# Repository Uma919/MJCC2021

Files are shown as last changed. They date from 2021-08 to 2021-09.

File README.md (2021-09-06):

# MJCC2021
## Overview
本リポジトリは[M5Stack Japan Creativity Contest 2021](https://info.switch-science.com/m5stack-creativity-contest-2021)開発リポジトリです．  
This repository is the development repository for [M5Stack Japan Creativity Contest 2021](https://info.switch-science.com/m5stack-creativity-contest-2021).  

紹介動画は下記サムネイルをクリック！  
(https://www.youtube.com/watch?v=NyVpVFx_jqs)

「Microparticle Sound Generator」は，ハウスダストやPM2.5をはじめとした微粒子の量をRGBLEDで可視化し，一定時間における時系列センサデータから音を生成して再生します．  
The Microparticle Sound Generator plays the generated sound with changes in the number of microparticles and also visualizes it by LED.  

## Concept
大気汚染区域では高周波音を流し，空気が澄んだ場所では心地よい？電子音を流すようにして，大気汚染区域に入らないようユーザーをナビゲートします．  
When you enter the air pollution zone, the device starts playing high-frequency sounds. On the other hand, the device will play soothing electronic sounds in the clean air area. So, the device will escort you while avoiding the air pollution zone.  
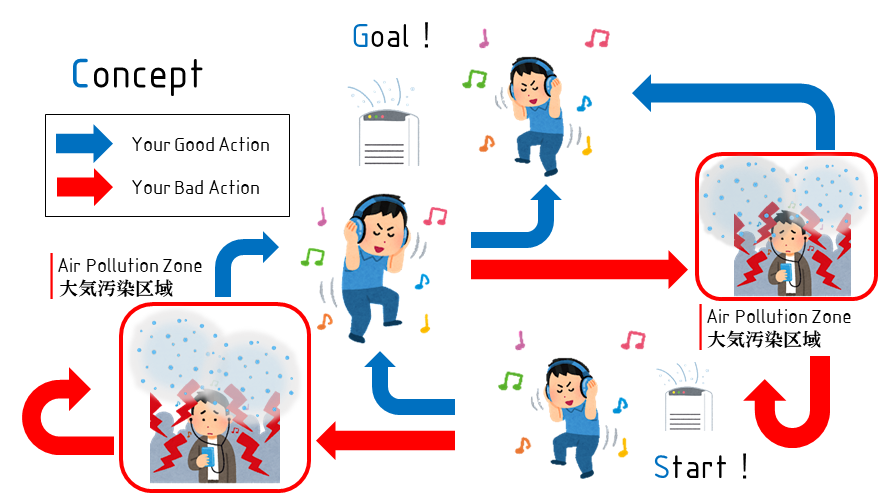
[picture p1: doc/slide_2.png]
  

## Features
本デバイスの主な特徴は，時系列センサデータを音に変換することにあります．これにより，多種多様な音を再生できるだけでなく，時々刻々と音を変化させることが可能となります．  
ATOM Liteには液晶ディスプレイが搭載されていないため、時系列センサデータを視覚的に表示することは困難です．加えて，移動中にモニターを見ることは危険です．従って，時系列センサデータを音に変換し、聴覚で案内することが適切だと考えられます．  
The main feature of the device is that it converts time-series sensor data into sound. It makes that it's possible not only to play a wide variety of sounds but also to change them from time to time.  
Since "ATOM Lite" isn't equipped with an LCD, it's difficult to display time-series sensor data visually. In addition, it's dangerous to look at the monitor while moving. So, I believe it is appropriate to convert the time-series sensor data into sound and guide the user through the auditory system.  
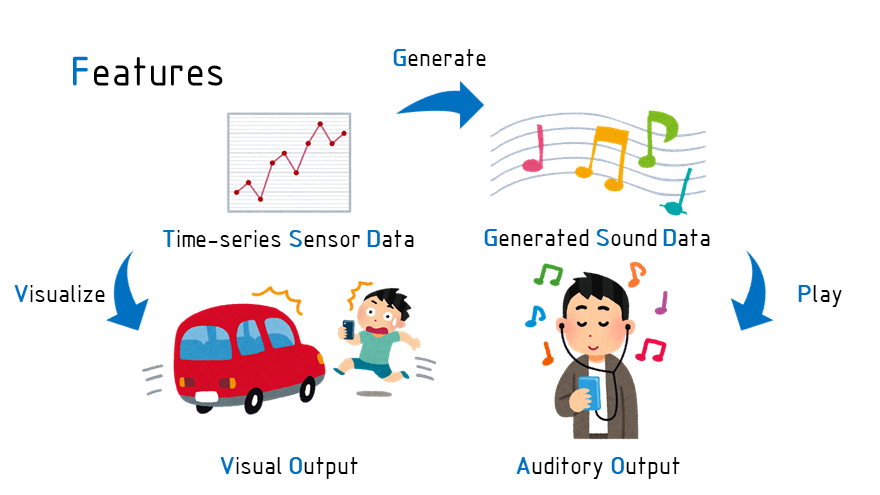
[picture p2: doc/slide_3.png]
  

## System Configuration
### 動作の流れ
1. ダストセンサにより微粒子濃度を計測する  
2. ATOM Liteにおいてセンサデータを保存し，それらに基づいて音を生成する  
3. ATOM SPKを用いて生成された音を流す  
### Operation Flow
1. Measure microparticle concentration with dust sensor
2. Storage sensor data in ATOM Lite and generate sound based on the data
3. Play the generated sound using ATOM SPK  
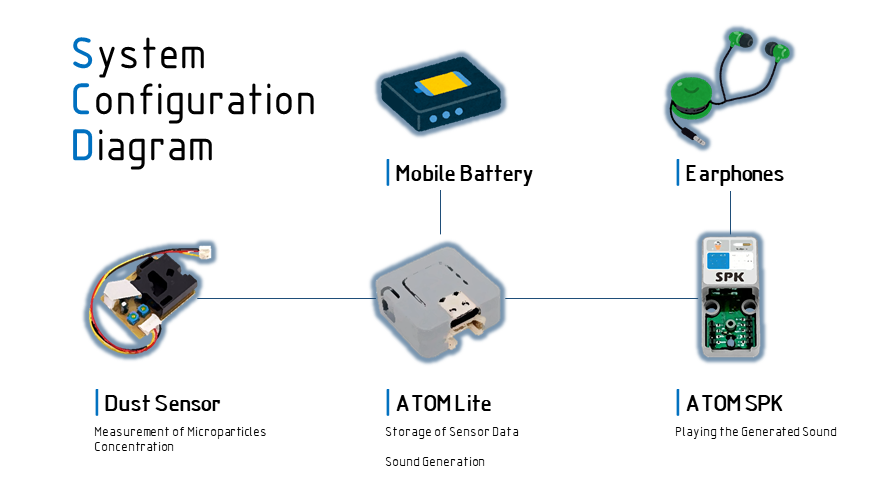
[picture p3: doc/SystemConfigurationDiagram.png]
  

## Equipment
### 制御基板や電子部品
* ATOM NS4168搭載 スピーカーキット  
  [販売ページ](https://ssci.to/7092)  
  [製品ページ](https://docs.m5stack.com/en/atom/atom_spk?id=product-features)    
* GROVE - Dust Sensor  
  [販売ページ](https://ssci.to/3081)  
  [製品ページ](https://wiki.seeedstudio.com/jp/Grove-Dust_Sensor/)  
  [データシート](https://files.seeedstudio.com/wiki/Grove_Dust_Sensor/resource/Grove_-_Dust_sensor.pdf)  
* モバイルバッテリー
* イヤホンやスピーカー
### 筐体部品等
* 筐体部品(3Dプリント)  
  [筐体部品1](./stl/3dp_parts_1.stl)  
  [筐体部品2](./stl/3dp_parts_2.stl) 
* [百均モバイルバッテリー(廃番の可能あり)](https://k-tai.watch.impress.co.jp/docs/review/1095722.html)取付部品(オプション)  
  [モバイルバッテリー取付部品](./stl/3dp_parts_3.stl)
* その他締結部品  
  M3ねじ  
  M3ナット  
  M3 20mmスペーサー

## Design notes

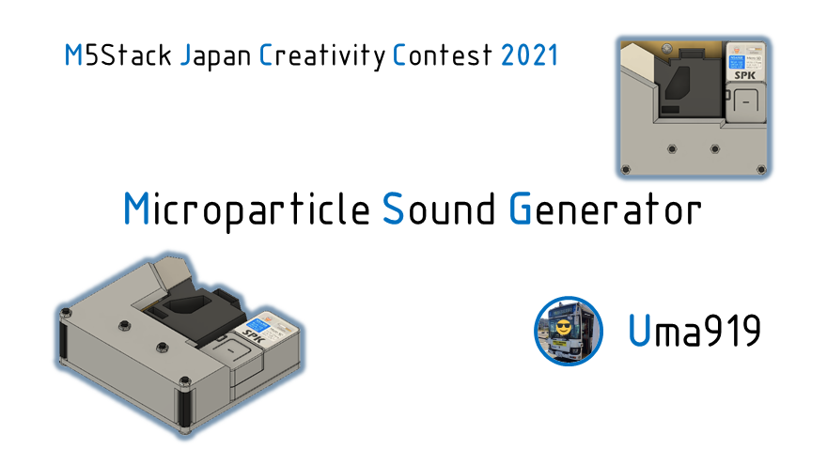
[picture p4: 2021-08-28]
doc/slide_1.png

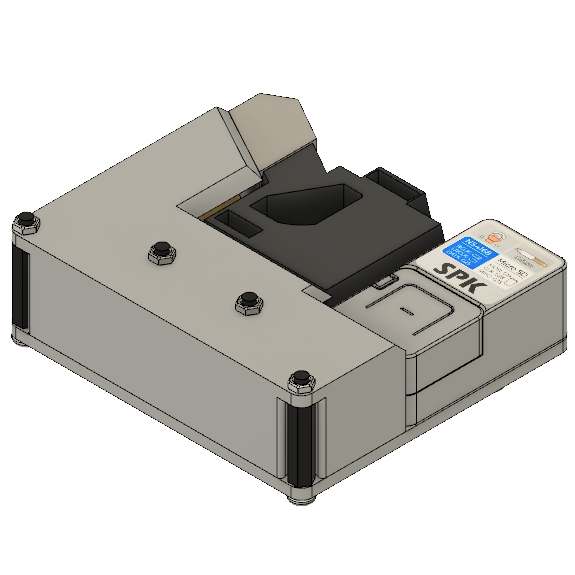
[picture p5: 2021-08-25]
doc/MicroparticleSoundGenerator_1.png

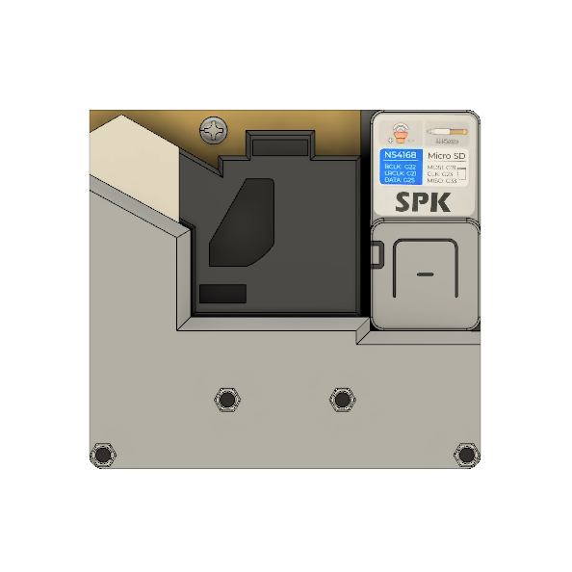
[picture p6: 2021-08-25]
doc/MicroparticleSoundGenerator_2.png

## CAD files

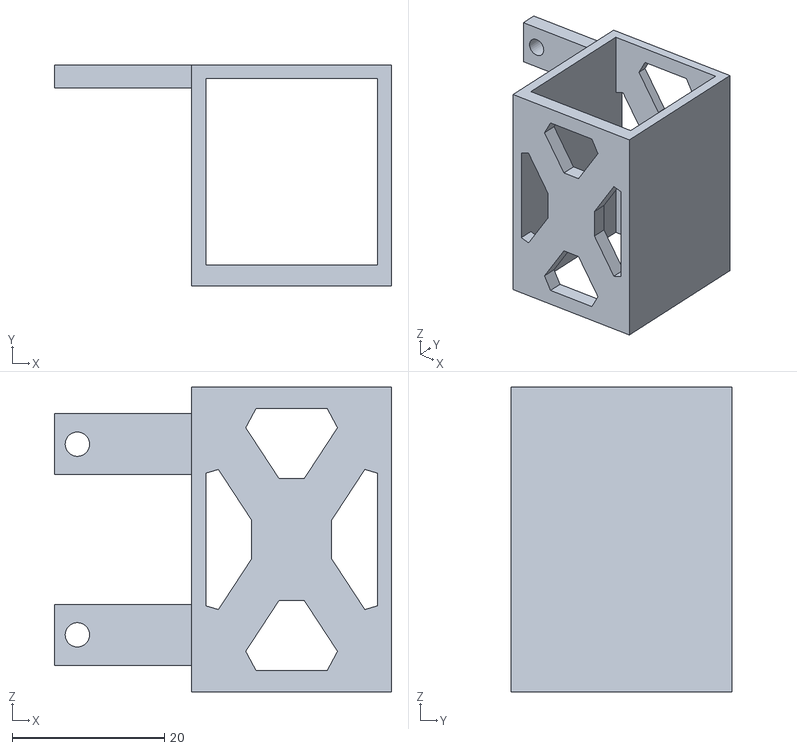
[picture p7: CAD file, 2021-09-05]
stl/3dp_parts_3.stl
44.2 x 29.0 x 40.0

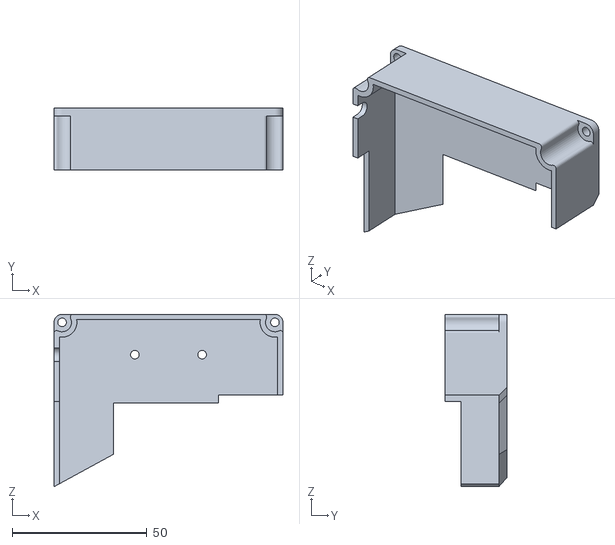
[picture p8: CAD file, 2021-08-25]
stl/3dp_parts_2.stl
85.0 x 23.0 x 64.0

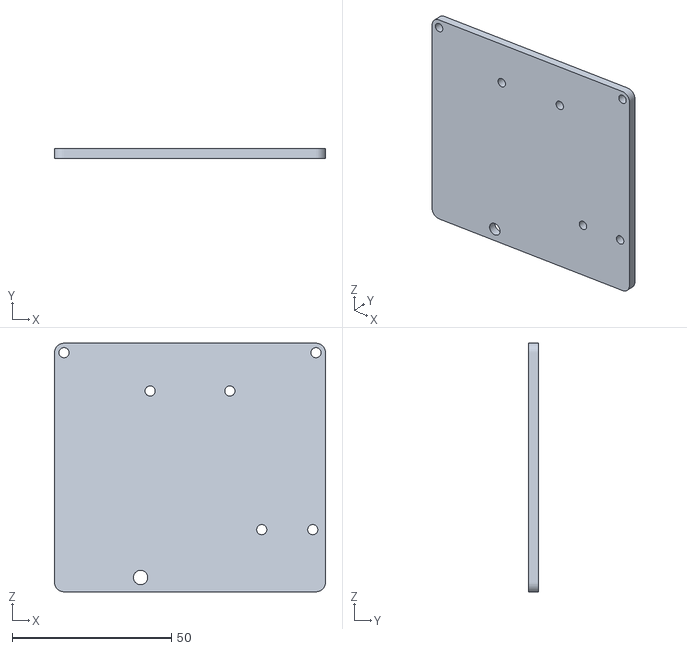
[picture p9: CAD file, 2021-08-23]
stl/3dp_parts_1.stl
85.0 x 3.00 x 78.0

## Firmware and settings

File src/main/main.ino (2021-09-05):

#include "M5Atom.h"
#include "AtomSPK.h"
#include "cppQueue.h"

ATOMSPK atomSPK;
cppQueue que(sizeof(float), 30, FIFO);

/*--- Sensor ---*/
int pin = 32;
unsigned long duration;
unsigned long starttime;
unsigned long sampletime_ms = 30000;  // sampele 30s ;
unsigned long lowpulseoccupancy = 0;
float ratio = 0;
float concentration = -1;

/*--- Sound Processing ---*/
void playSound(){
    float TmpData[30];
    for(int i = 0; i < sizeof(TmpData) / sizeof(float); i ++) TmpData[i] = -1;
    
    /* Extract Sensor Data */
    int idx = 0;
    while(que.isEmpty() == false){
        float popTmpData;
        que.pop(&popTmpData);
        TmpData[idx] = popTmpData;
        idx ++;
        if((sizeof(TmpData) / sizeof(float)) == idx) break;
    }
    
    /* Play Sound */
    if(TmpData[0] !=  -1){
        for(int i = 0; i < sizeof(TmpData) / sizeof(float); i ++){
            if(TmpData[i] !=  -1){
                float pushTmpData = TmpData[i];
                float dt = constrain(pushTmpData, 0, 3000);
                float f_map = map(dt, 0, 3000,  500, 3000);
                float v_map = map(dt, 0, 3000, 5000, 1500);
                que.push(&pushTmpData);
                atomSPK.playBeep(int(f_map), 100, int(v_map), false);  // Play Sound
                delay(100);
            }
        }
        M5.dis.drawpix(0, 0xffffff);  // White Color LED
        delay(100);
    }
}

/*--- Main Program ---*/
void setup(){
    /* ATOM Lite */
    M5.begin(true, false, true);

    /* Debug */
    Serial.begin(9600);

    /* Sensor */
    pinMode(pin, INPUT);
    starttime = millis();  // get the current time;

    /* Speaker */
    atomSPK.begin();
}

void loop(){
    /* Sensor */
    duration = pulseIn(pin, LOW);
    lowpulseoccupancy = lowpulseoccupancy + duration;

    if((millis() - starttime) > sampletime_ms){  //if the sample time == 30s
        ratio = lowpulseoccupancy / (sampletime_ms * 10.0);  // Integer percentage 0=>100
        concentration = 1.1 * pow(ratio, 3) - 3.8 * pow(ratio, 2) + 520 * ratio + 0.62;  // using spec sheet curve
        
        float popData;
        if(que.isFull()){
            que.pop(&popData);
        }
        que.push(&concentration);

        /* Debug */
        //Serial.print("push: ");
        //Serial.print(concentration);
        //Serial.print(", pop: ");
        //Serial.println(popData);
        
        lowpulseoccupancy = 0;
        starttime = millis();
    }
 
    /* Speaker */
    playSound();
    
    /* RGB LED */
    if(concentration >= 2000){
        M5.dis.drawpix(0, 0x00ff00);  // Red Color LED
    }else if(2000 > concentration && concentration > 1000){
        M5.dis.drawpix(0, 0xffff00);  // Yellow Color LED
    }else if(1000 >= concentration && concentration >= 0){
        M5.dis.drawpix(0, 0xff0000);  // Green Color LED
    }
}

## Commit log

2021-08-15 必要物品の列記
2021-08-15 商品URL修正
2021-08-15 方針転換
2021-08-15 音声ファイルの追加
2021-08-22 ソースコード追加
2021-08-22 ソースコード修正
2021-08-22 完成イメージ図の追加
2021-08-22 README.md修正
2021-08-23 3Dプリントパーツの追加
    [3dp_parts_1.stl, 3dp_parts_2.stl]
2021-08-23 README.mdの修正
2021-08-25 STLファイルの修正
    [3dp_parts_2.stl]
2021-08-28 システム構成図の追加
2021-08-28 システム構成図の修正
2021-08-28 コンセプトの追加
2021-08-28 画像の修正
2021-08-28 ソースコードの修正
2021-08-28 システム構成図の変更
2021-08-28 README.mdの追記
2021-08-28 装置の特徴の追記
2021-09-05 ソースコード修正とオプションパーツの追加
    [3dp_parts_3.stl]
2021-09-05 README修正
